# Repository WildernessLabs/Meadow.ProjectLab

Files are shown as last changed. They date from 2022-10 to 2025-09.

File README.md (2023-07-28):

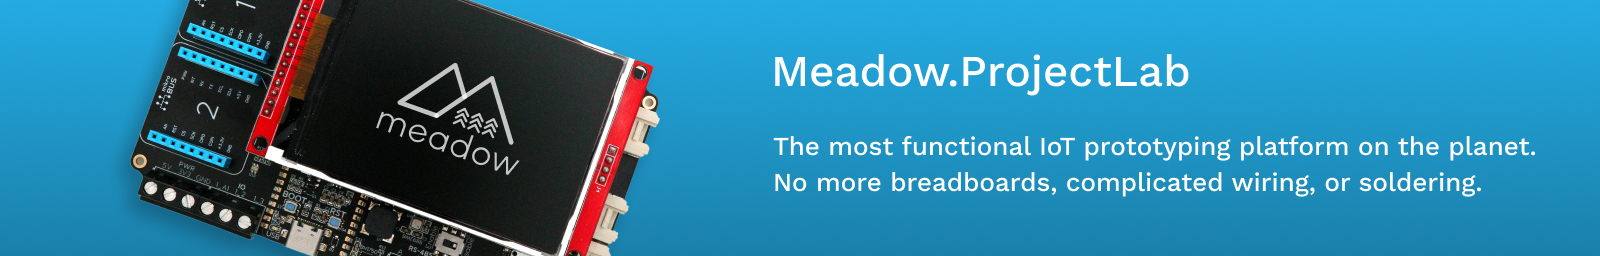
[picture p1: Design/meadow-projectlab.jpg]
Meadow.ProjectLab, C#, iot


# Meadow.ProjectLab

Project Lab is the most functional IoT prototyping platform on the planet. No more breadboards, complicated wiring, or soldering. Project Lab was built from the ground up using the industry's most powerful, capable, and reliable sensors, components, and connectors.

## Contents
* [Purchasing or Building](#purchasing-or-building)
* [Getting Started](#getting-started)
* [Hardware Specifications](#hardware-specifications)
* [Pinout Diagram](#pinout-diagram)
  * [Project Lab v3.e](#project-lab-v3e)
  * [Project Lab v2.e](#project-lab-v2e)
  * [Project Lab v1.e](#project-lab-v1e)
* [Industrial Enclosure Design](#industrial-enclosure-design)
* [Additional Samples](#additional-samples)
* [Support](#support)

## Purchasing or Building

<table width="100%">
    <tr>
        <td>
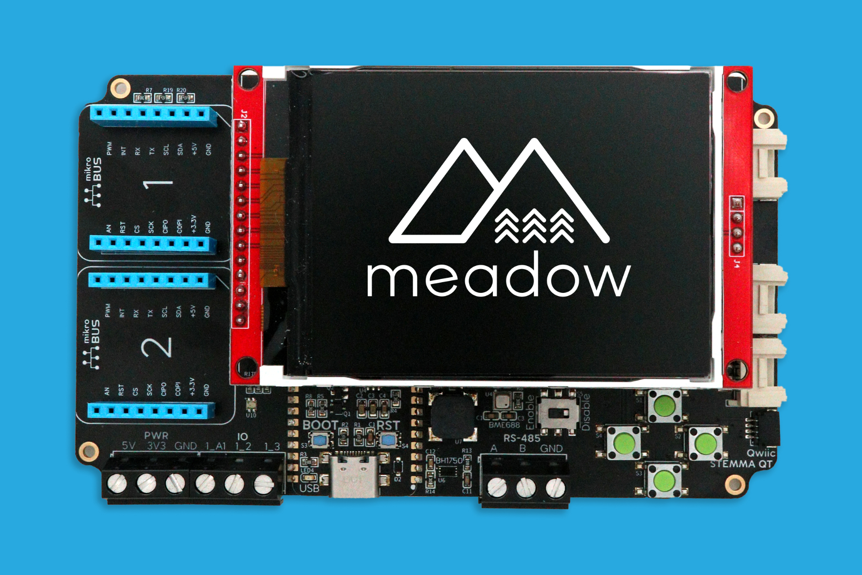
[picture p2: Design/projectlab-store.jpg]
ProjectLab, C#, iot
            
        </td>
        <td>
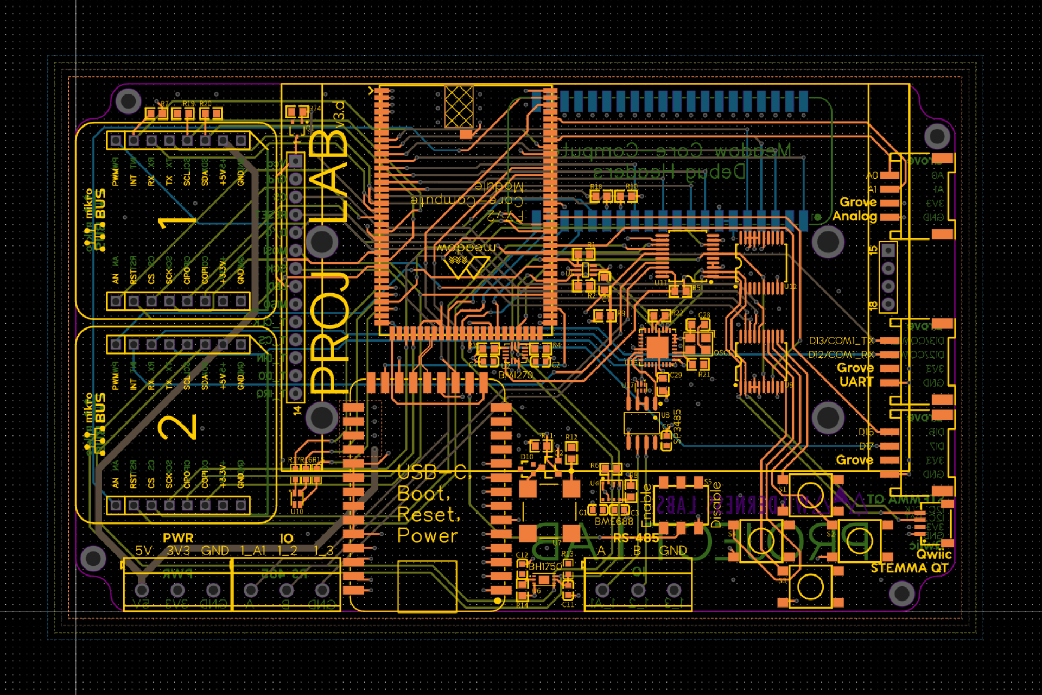
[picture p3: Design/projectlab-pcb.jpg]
ProjectLab, C#, iot
             
        </td>
    </tr>
    <tr>
        <td>
            You can get a Project Lab fully assembled from the <a href="https://store.wildernesslabs.co/collections/frontpage/products/project-lab-board">Wilderness Labs store</a>.
        </td>
        <td> 
            It's also designed so that it can be assembled at home for the adventurous. All design files can be found in the <a href="/Hardware">Hardware Design</a> folder.
        </td>
    </tr>
</table>

## Getting Started

To make using the hardware even simpler, we've created a Nuget package that instantiates and encapsulates the onboard hardware into a `ProjectLab` class.

1. Add the ProjectLab Nuget package your project: 
    - `dotnet add package Meadow.ProjectLab`, or
    - [Meadow.ProjectLab Nuget Package](https://www.nuget.org/packages/Meadow.ProjectLab)
    - [Explore in Fuget.org](https://www.fuget.org/packages/Meadow.ProjectLab/0.1.0/lib/netstandard2.1/ProjectLab.dll/Meadow.Devices/ProjectLab)

2. Instantiate the `ProjectLab` class:  
```csharp
public class MeadowApp : App<F7FeatherV2>
{
    IProjectLabHardware projLab;

    public override Task Initialize()
    {
        projLab = ProjectLab.Create();
        ...
```

3. To Access the `Project Lab` onboard peripherals:
```csharp
    if (projLab.EnvironmentalSensor is { } bme688)
    {
        bme688.Updated += Bme688Updated;
        bme688.StartUpdating(TimeSpan.FromSeconds(5));
    }
```

4. To use an I2C peripheral (with a [Grove Character display](https://wiki.seeedstudio.com/Grove-16x2_LCD_Series) as an example):
```csharp
    var display = new CharacterDisplay
    (
        i2cBus: projLab.I2cBus,
        address: (byte)I2cCharacterDisplay.Addresses.Grove,
        rows: 2, columns: 16,
        isGroveDisplay: true
    );
```

## Hardware Specifications

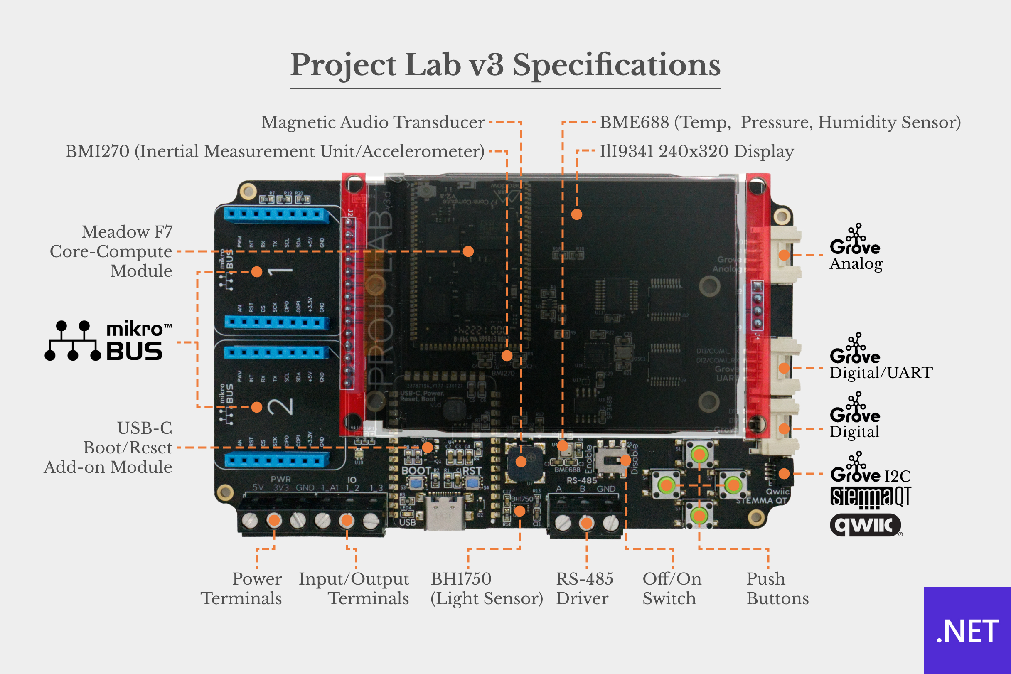
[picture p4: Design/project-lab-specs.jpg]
project-lab, specs, iot, dotnet


<table>
    <tr>
        <th>Onboard Peripherals</th>
        <th>Connectivity</th>
    </tr>
    <tr>
        <td><strong>ILI9341</strong> - SPI 320x240 color display</li></td>
        <td><strong>MikroBUS</strong> - Two sets of MikroBUS pin headers</td>
    </tr>
    <tr>
        <td><strong>BMI270</strong> - I2C motion and acceleration sensor</td>
        <td><strong>Qwiic</strong> - Stemma QT I2C connector</td>
    </tr>
    <tr>
        <td><strong>BH1750</strong> - I2C light sensor</td>
        <td><strong>Grove</strong> - Analog header</td>
    </tr>
    <tr>
        <td><strong>BME688</strong> - I2C atmospheric sensor</td>
        <td><strong>Grove</strong> - GPIO/serial header</td>
    </tr>
    <tr>
        <td><strong>Push Button</strong> - 4 momentary buttons</td>
        <td><strong>RS-485</strong> - Serial</td>
    </tr>
    <tr>
        <td><strong>Magnetic Audio Transducer</strong> - High quality piezo speaker</td>
        <td><strong>Ports</strong> - 3.3V, 5V, ground, one analog and two GPIO ports</td>
    </tr>
</table>

You can find the schematics and other design files in the [Hardware folder](/Hardware).

## Pinout Diagram

Check the diagrams below to see what pins on the Meadow are connected to every peripheral on board and its connectors:
&nbsp;

### Project Lab v3.e

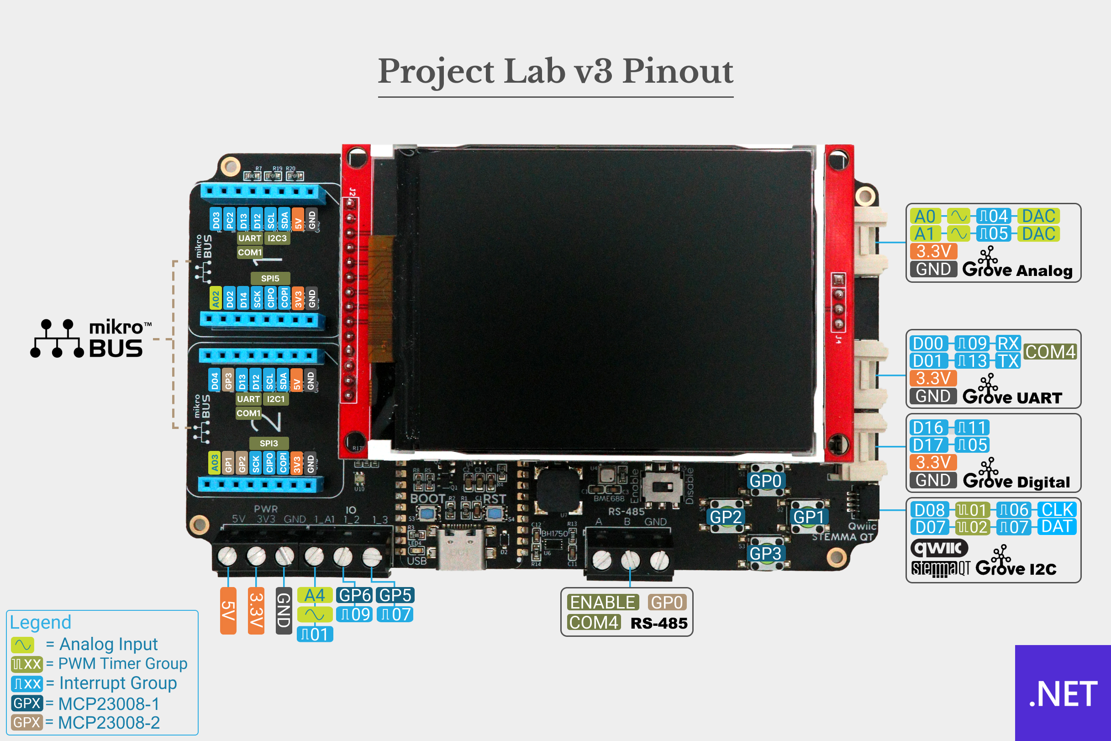
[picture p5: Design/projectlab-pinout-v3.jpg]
project-lab-v3, pinout, iot, dotnet


### Project Lab v2.e

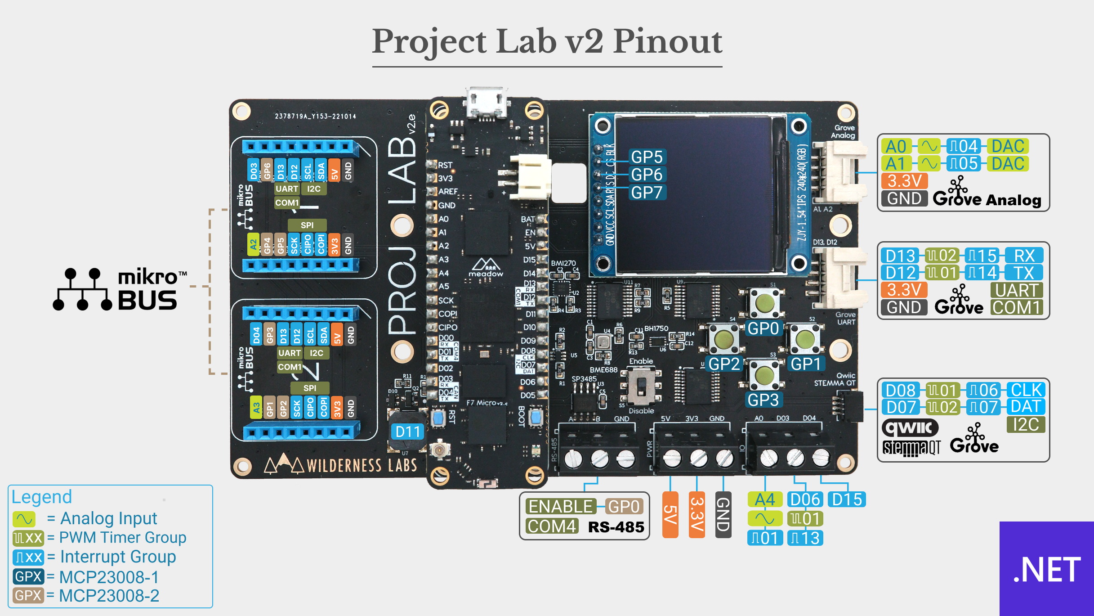
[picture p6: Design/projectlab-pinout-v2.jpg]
project-lab-v2, specs, iot, dotnet


### Project Lab v1.e

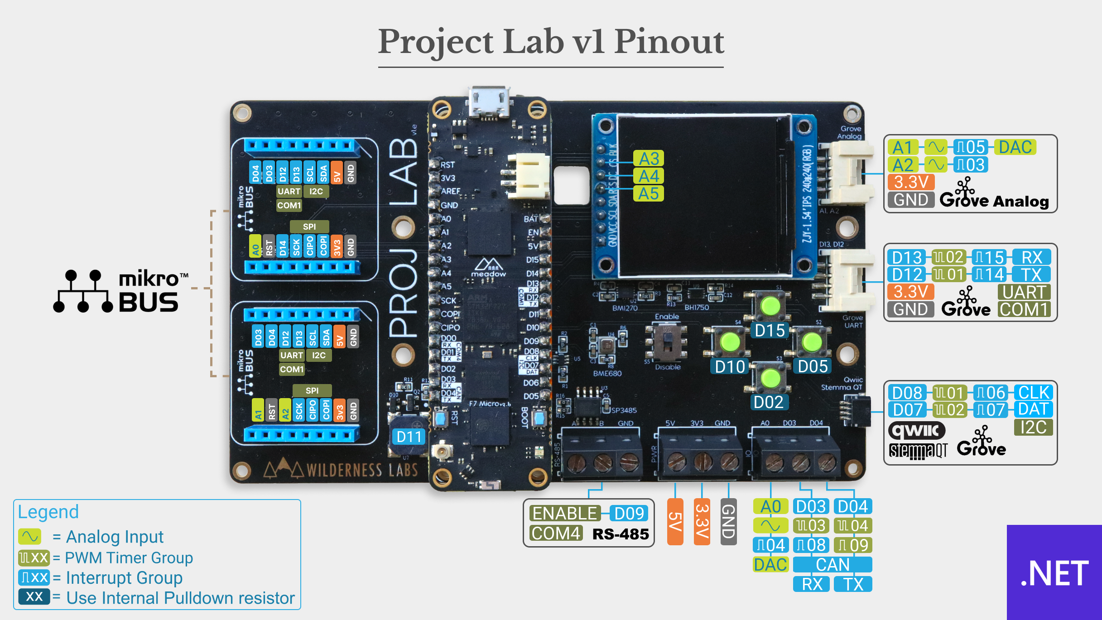
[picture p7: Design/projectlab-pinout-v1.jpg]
project-lab-v1, specs, iot, dotnet


## Industrial Enclosure Design

The enclosure was designed in Autodesk Fusion 360. The source file can be found and STL files can be found [here](Design/Enclosure/STLs_For_Printing/).

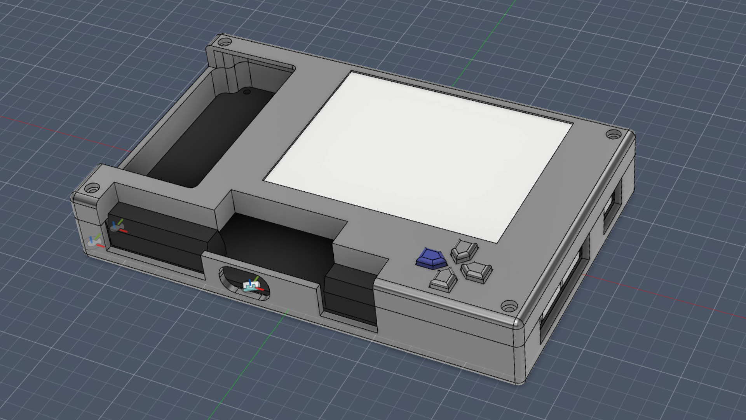
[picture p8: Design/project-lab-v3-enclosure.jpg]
project-lab, enclosure, 3d-print, iot


## Additional Samples

1. **[Setup your Meadow Build Environment](http://developer.wildernesslabs.co/Meadow/Getting_Started/Deploying_Meadow/)** - If you haven't deployed a Meadow app before, you'll need to setup your IDE extension(s), deploy Meadow.OS, etc.
2. **[Run the Demo App](Source/ProjectLab_Demo)** - Deploy the Project Lab demonstration app to see the built in peripherals at work.
3. **[Check out the Project Lab Samples](https://github.com/WildernessLabs/Meadow.ProjectLab.Samples)** - We recommend cloning the [Meadow.ProjectLab.Samples](https://github.com/WildernessLabs/Meadow.ProjectLab.Samples) repo. There you'll find a bunch of awesome samples that you can run right out-of-the box! 
<a href="https://github.com/WildernessLabs/Meadow.ProjectLab.Samples">
    project-lab, iot, project, samples
</a>

## Support

Having trouble building/running these projects? 
* File an [issue](https://github.com/WildernessLabs/Meadow.Desktop.Samples/issues) with a repro case to investigate, and/or
* Join our [public Slack](http://slackinvite.wildernesslabs.co/), where we have an awesome community helping, sharing and building amazing things using Meadow.

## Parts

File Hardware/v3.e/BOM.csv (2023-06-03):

ID | Name | Designator | Footprint | Quantity | Manufacturer Part | Manufacturer | Supplier | Supplier Part | Price
1 | 0.1u | C1,C2,C3,C4,C5,C11,C12 | C0603 | 7 | CC0603KRX7R9BB103 | Yageo
2 | 0.1µf | C7 | C0603 | 1 | CC0603KRX7R7BB104 | YAGEO | LCSC | C108079 | 0.003
3 | 0.1u | C28,C29 | C0603 | 2 | CC0603KRX7R7BB104 | Yageo
4 | SM04B-SRSS-TB (LF)(SN) | CN1 | CONN-SMD_4P-P1.00_SM04B-SRSS-TB-LF-SN | 1 | SM04B-SRSS-TB (LF)(SN) | JST Sales America | LCSC | C160404 | 0.178
5 | BAS70KFILM | D10 | SOT323 | 1 | BAS70KFILM | ST Microelectronics
6 | 1125R-SMT-4P | J1,J2,J3 | HW4-SMD-2.0-90D | 3 | 1125R-SMT-4P
7 | 1.8432MHz | OSC1 | OSC-SMD_4P-L3.2-W2.5-CJ13-320001210A20 | 1 | ASE-1.8432MHZ-LC-T | ABRACON
8 | CONN-TH_3P-P5.00 | P1,P2,P3 | CONN-TH_3P-P5.00 | 3 | 39890-0303 | Molex | Digi-Key | WM15826-ND
9 | MCH3374-TL-E | Q1 | -ONSC-MCPH-3_V | 1 | MCH3374-TL-E | OnSemi
10 | FDV305N | Q2 | SOT-23_L2.9-W1.3-P0.95-LS2.4-BR | 1 | FDV305N | Fairchild |  | C65189 | 0.034
11 | 10k | R1,R2,R3,R4,R5,R6,R7,R8,R9,R14,R21,R74 | R0603 | 12 | RC0603FR-0710KL | Yageo
12 | 0 | R10,R18 | R0603 | 2 | RC0603JR-070RL | Yageo
13 | 10kΩ | R11 | R0603 | 1 | RC0603FR-0710KL | Yageo
14 | 20Ω | R12 | R0603 | 1 | RC0603FR-0720RL | Yageo
15 | 1k | R13,R22 | R0603 | 2 | RC0603FR-071KL | Yageo
16 | 300 | R15,R16 | R0603 | 2 | RC0603FR-07300RL | Yageo
17 | 620 | R17 | R0603 | 1 | RC0603FR-07620RL | Yageo
18 | 4.7kΩ | R19,R20 | R0603 | 2 | RC0603FR-074K7L | Yageo
19 | Up | S1 | TACTILE_SWITCH_TALL | 1
20 | Down | S2,S3,S4 | TACTILE_SWITCH_TALL | 3
21 | 452403012014 | S5 | 452403012014 | 1 | 452403012014 | Wurth Elektronik
22 | Meadow F7v2 Core-Compute Module - Logical | U1 | MEADOW_F7V2_CORE_COMPUTE | 1 |  | Wilderness Labs
23 | BMI270 | U2 | LGA-14_L3.0-W2.5-P0.50-BR | 1 | BMI270 | null | LCSC | C2836813 | 1.877
24 | SP3485CN-L | U3 | SOIC-8_L4.9-W3.9-P1.27-LS6.0-BL | 1 | SP3485CN-L | MaxLinear | LCSC | C916153 | 7.804
25 | BME688 | U4 | LGA-8_L3.0-W3.0-P0.80-TR | 1 | BME688 | Bosch Sensortec
26 | LTC4311ISC6 | U5 | SC-70-6_L2.2-W1.3-P0.65-LS2.2-BL | 1 | LTC4311ISC6#TRPBF
27 | BH1750FVI-TR | U6 | WSOF-6_L2.6-W1.6-P0.50-TL-EP | 1 | BH1750FVI-TR | ROHM | LCSC | C78960 | 0.942
28 | CMT-7525-80-SMT | U7 | CMT-7525S | 1 | CMT-7525-80-SMT | CUI Devices
29 | MCP23008T-E/SS | U9,U11,U12 | SSOP-20_L7.2-W5.3-P0.65-LS7.8-TL | 3 | MCP23008T-E/SS | Microchip Tech | LCSC | C629435 | 1.979
30 | LTST-C19HE1WT | U10 | LED-ARRAY-SMD_0603-4P-L1.6-W1.6-BL-RD | 1 | LTST-C19HE1WT-H | Lite-On | LCSC | C427425 | 0.066
31 | Meadow Core-Compute USB-C, Power, Boot, and Reset Addon Module | U13 | MEADOW CORE-COMPUTE USB-C, POWER, BOOT, RESET ADDON MODULE | 1 |  | Wilderness Labs
32 | ILI9341 LCD TFT 3.2 | U14 | ILI9341 TFT LCD 3.2" - NO BOLT HOLES | 1 | ILI9341 LCD TFT 3.2
33 | MEADOW F7 DEBUG ADDON MODULE | U15 | MEADOW F7 DEBUG ADDON MODULE | 1
34 | SC16IS752IBS,128 | U16 | HVQFN-32_L5.0-W5.0-P0.50-TL-EP3.1 | 1 | SC16IS752IBS,128 | NXP(恩智浦) | LCSC | C2678025 | 5.306
35 | NC7S04L6X | U17 | MICROPAK-6_L1.5-W1.0-P0.50-BR | 1 | NC7S04L6X | onsemi(安森美) | LCSC | C895519 | 0.189

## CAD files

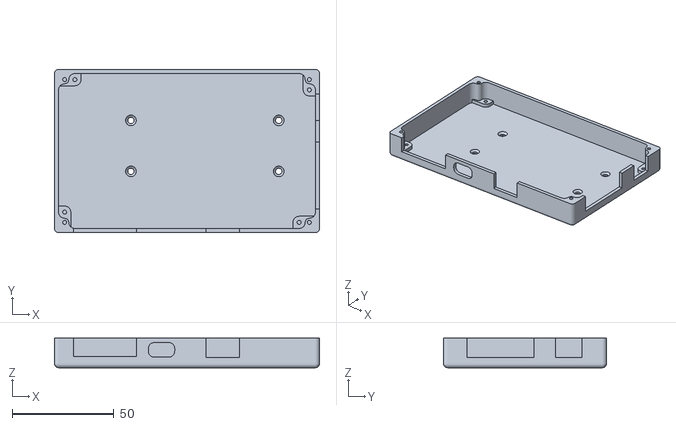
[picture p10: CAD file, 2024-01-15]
Design/Enclosure/STLs_For_Printing/PL_Enclosure_Bottom_w_DIN_Mount.stl
130.0 x 80.0 x 14.5

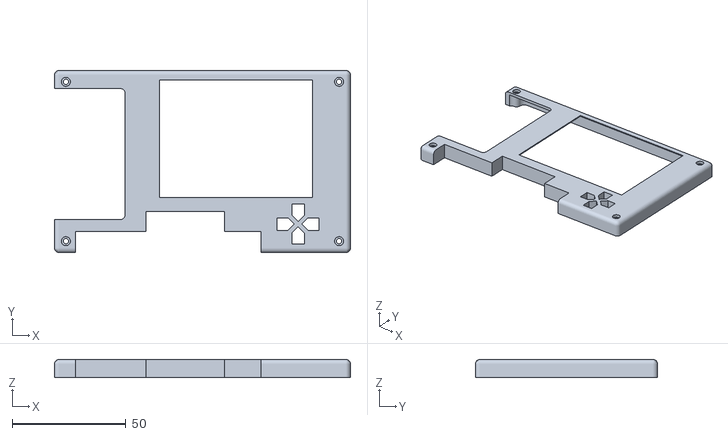
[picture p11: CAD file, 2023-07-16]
Design/Enclosure/STLs_For_Printing/PL_Enclosure_Top.stl
130.0 x 80.0 x 8.00

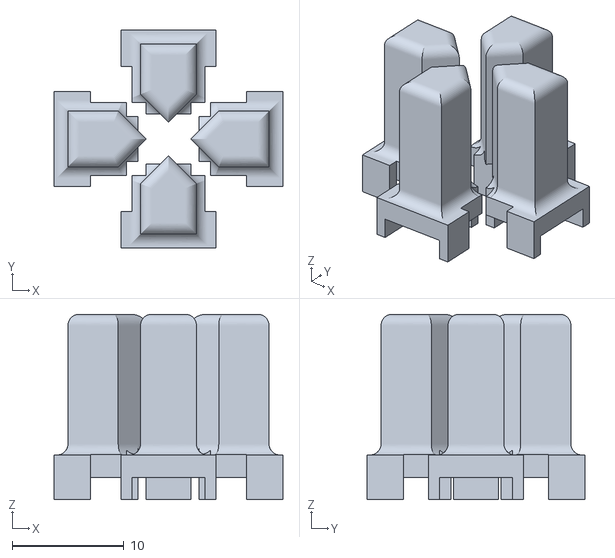
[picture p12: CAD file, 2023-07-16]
Design/Enclosure/STLs_For_Printing/PL_D-Pad_2.stl
20.5 x 19.5 x 16.6

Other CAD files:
Design/Enclosure/STLs_For_Printing/PL_Enclosure_Bottom.stl
Design/Enclosure/Source/PLv3 Enclosure w DIN Mounts.f3z
Design/Enclosure/Source/PLv3 Enclosure.f3z

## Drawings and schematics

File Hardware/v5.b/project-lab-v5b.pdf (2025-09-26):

# I2C1 Accelerator + Pull-ups

# Grove Analog/Digital

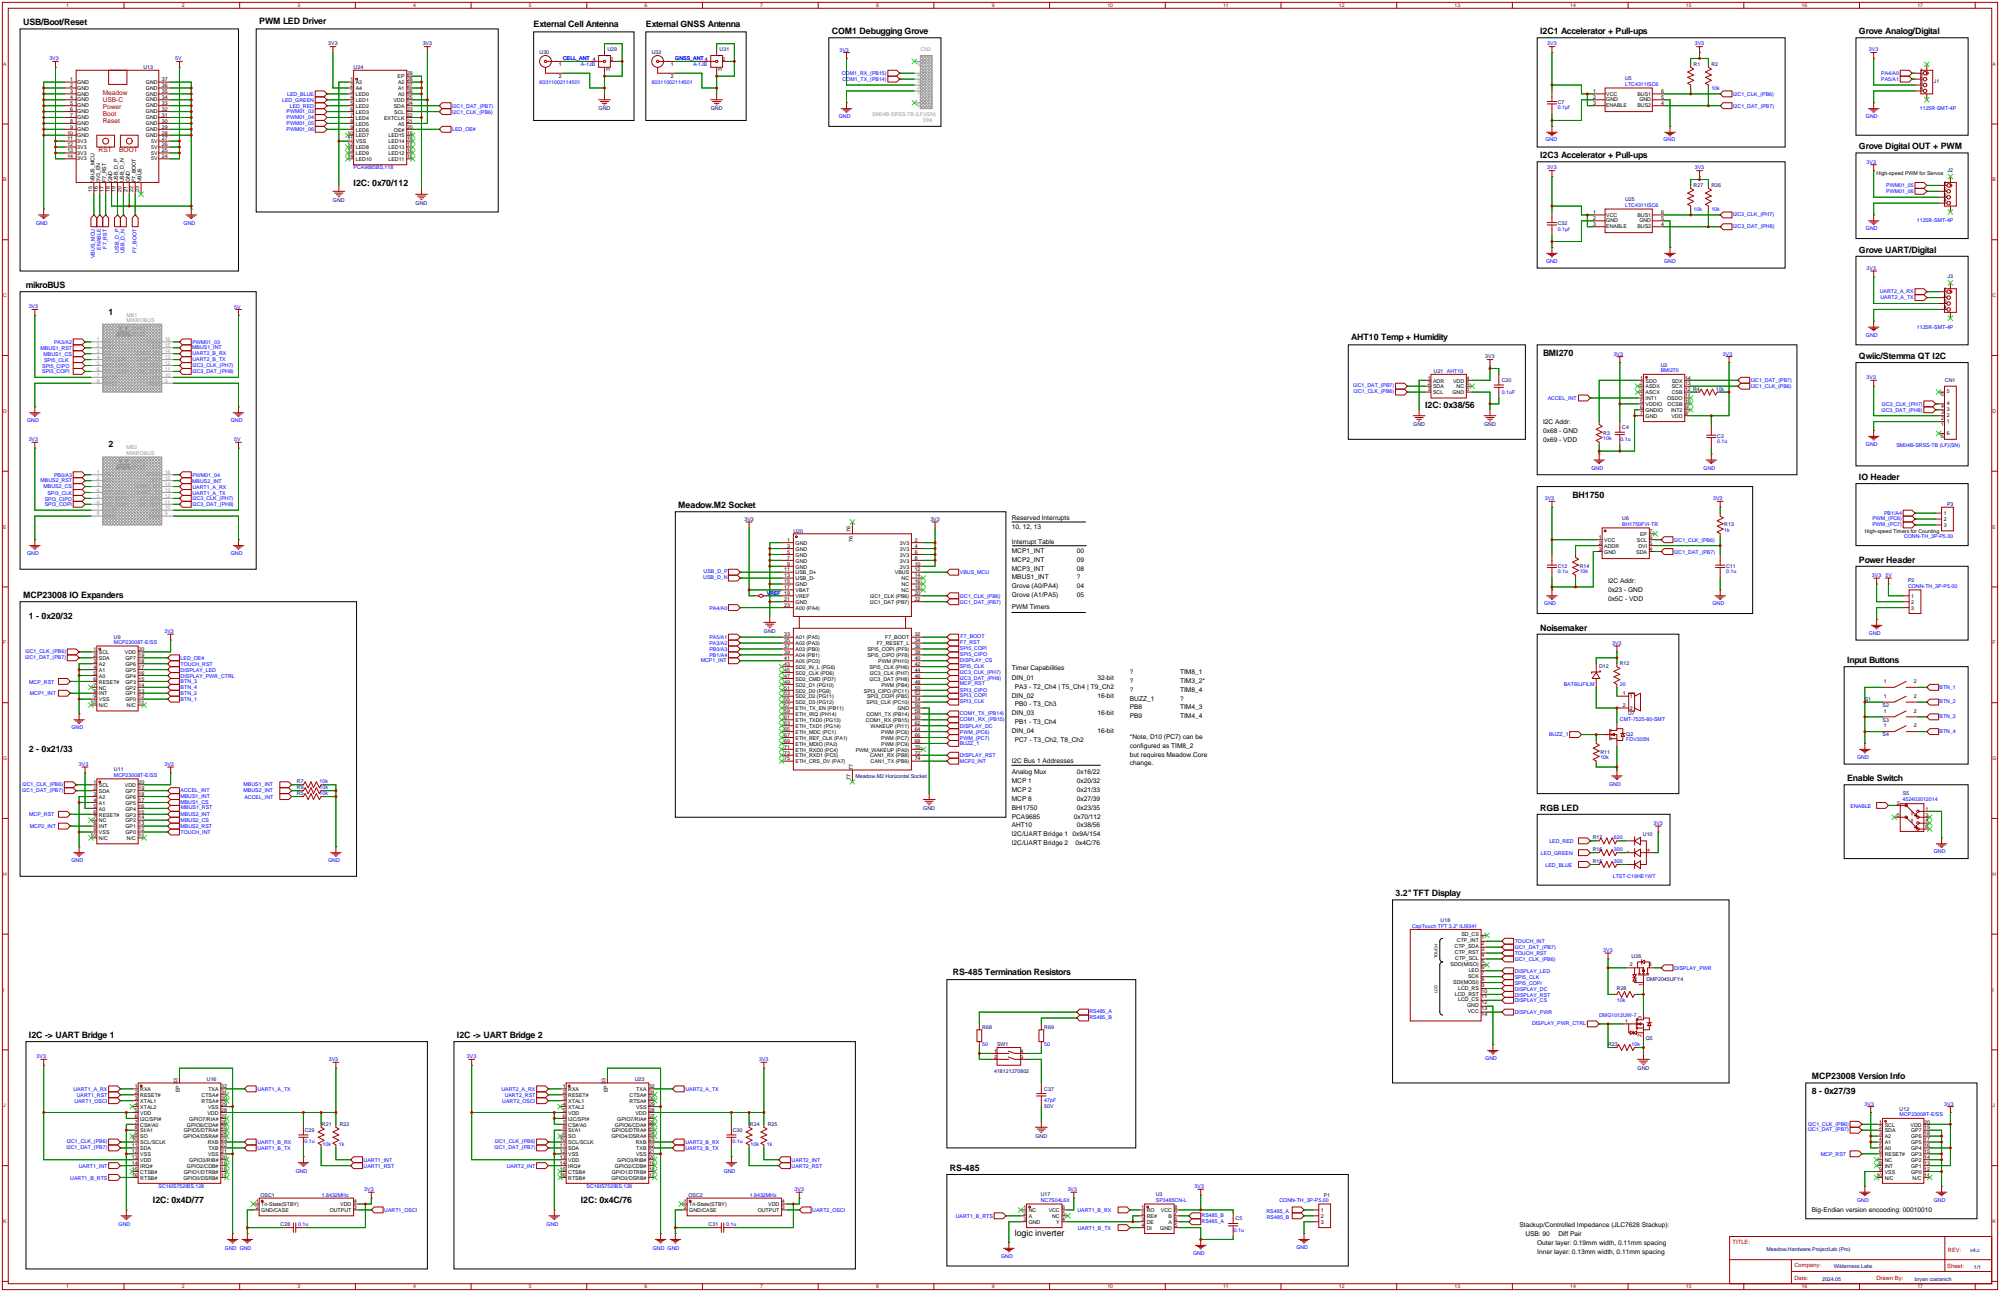
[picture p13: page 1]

5V 24 5V 25 5V 26 5V 27 GND 28 GND 29 GND 30 GND 31 GND 32 GND 33 GND 34 GND 35 GND 36 GND 37

SM04B-SRSS-TB (LF)(SN)

Grove Digital OUT + PWM

*Note, D10 (PC7) can be
configured as TIM8_2
but requires Meadow.Core
change.

Big-Endian version encooding: 00010010

Stackup/Controlled Impedance (JLC7628 Stackup):
USB: 90 Diff Pair
Outer layer: 0.19mm width, 0.11mm spacing
Inner layer: 0.13mm width, 0.11mm spacing

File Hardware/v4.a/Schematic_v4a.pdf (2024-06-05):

BME 688 | 3V3

# I2C Accel Pull-Ups

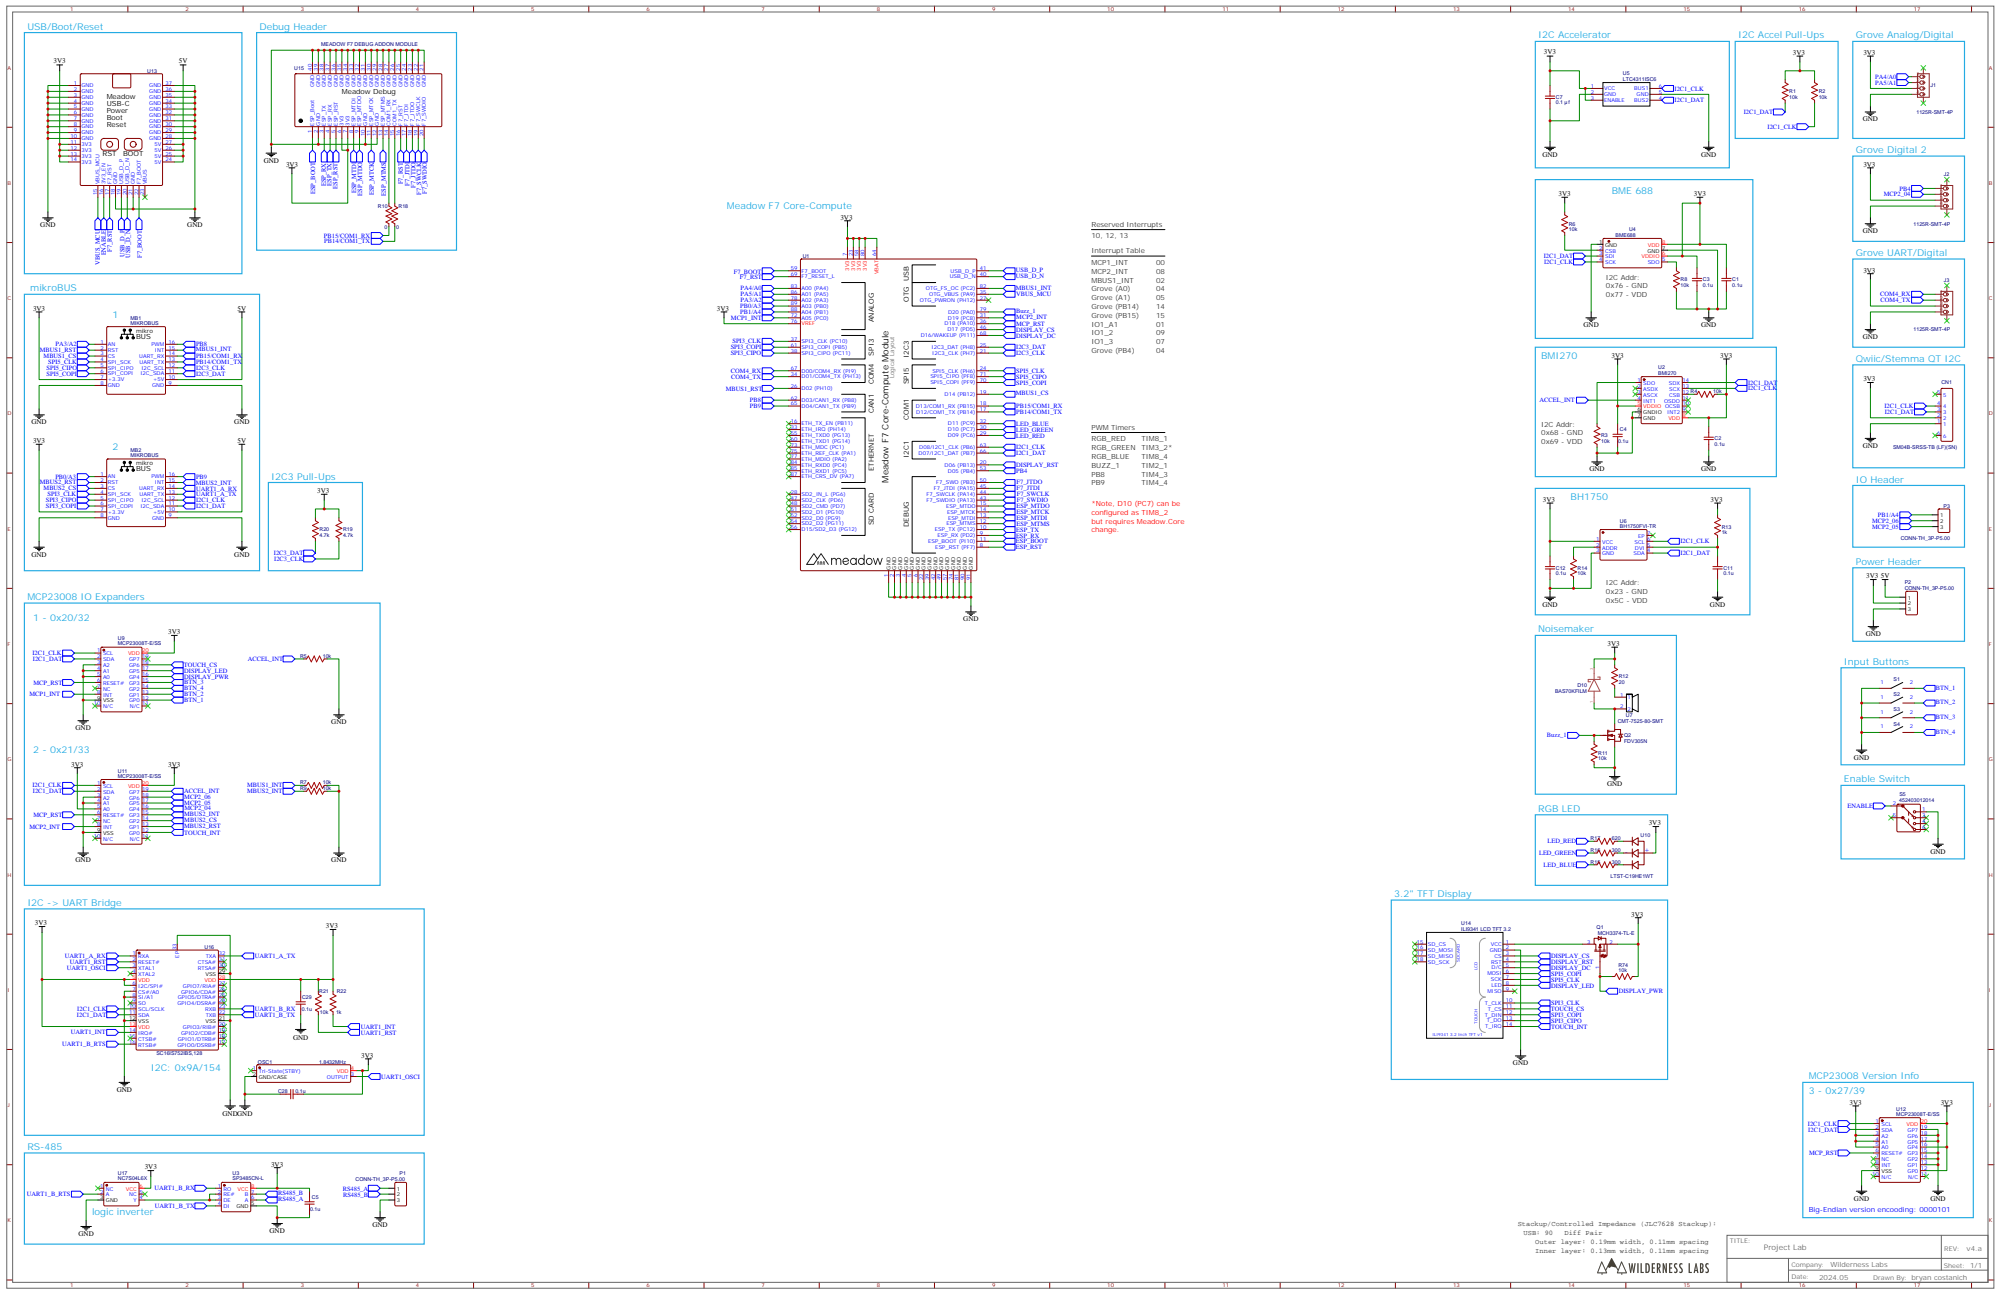
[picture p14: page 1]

MEADOW F7 DEBUG ADDON MODULE

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

F7_SWDIO 20 GND 21 GND 22 GND 23 GND 24 GND 25 GND 26 GND 27 GND 28 GND 29 GND 30 GND 31 GND 32 GND 33 GND 34 GND 35 GND 36 GND 37 GND 38 GND 39 GND 40

Meadow F7 Core-Compute Module

GND 6 GND 5 GND 4 GND 3 GND 2 GND 1 Logical Layout

SM04B-SRSS-TB (LF)(SN)

*Note, D10 (PC7) can be
configured as TIM8_2
but requires Meadow.Core
change.

Big-Endian version encooding: 0000101

Stackup/Controlled Impedance (JLC7628 Stackup):
Outer layer: 0.19mm width, 0.11mm spacing
Inner layer: 0.13mm width, 0.11mm spacing

Drawn By: bryan costanich

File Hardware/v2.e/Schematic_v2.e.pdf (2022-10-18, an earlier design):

# I2C Pull-Ups

## Interrupt Table

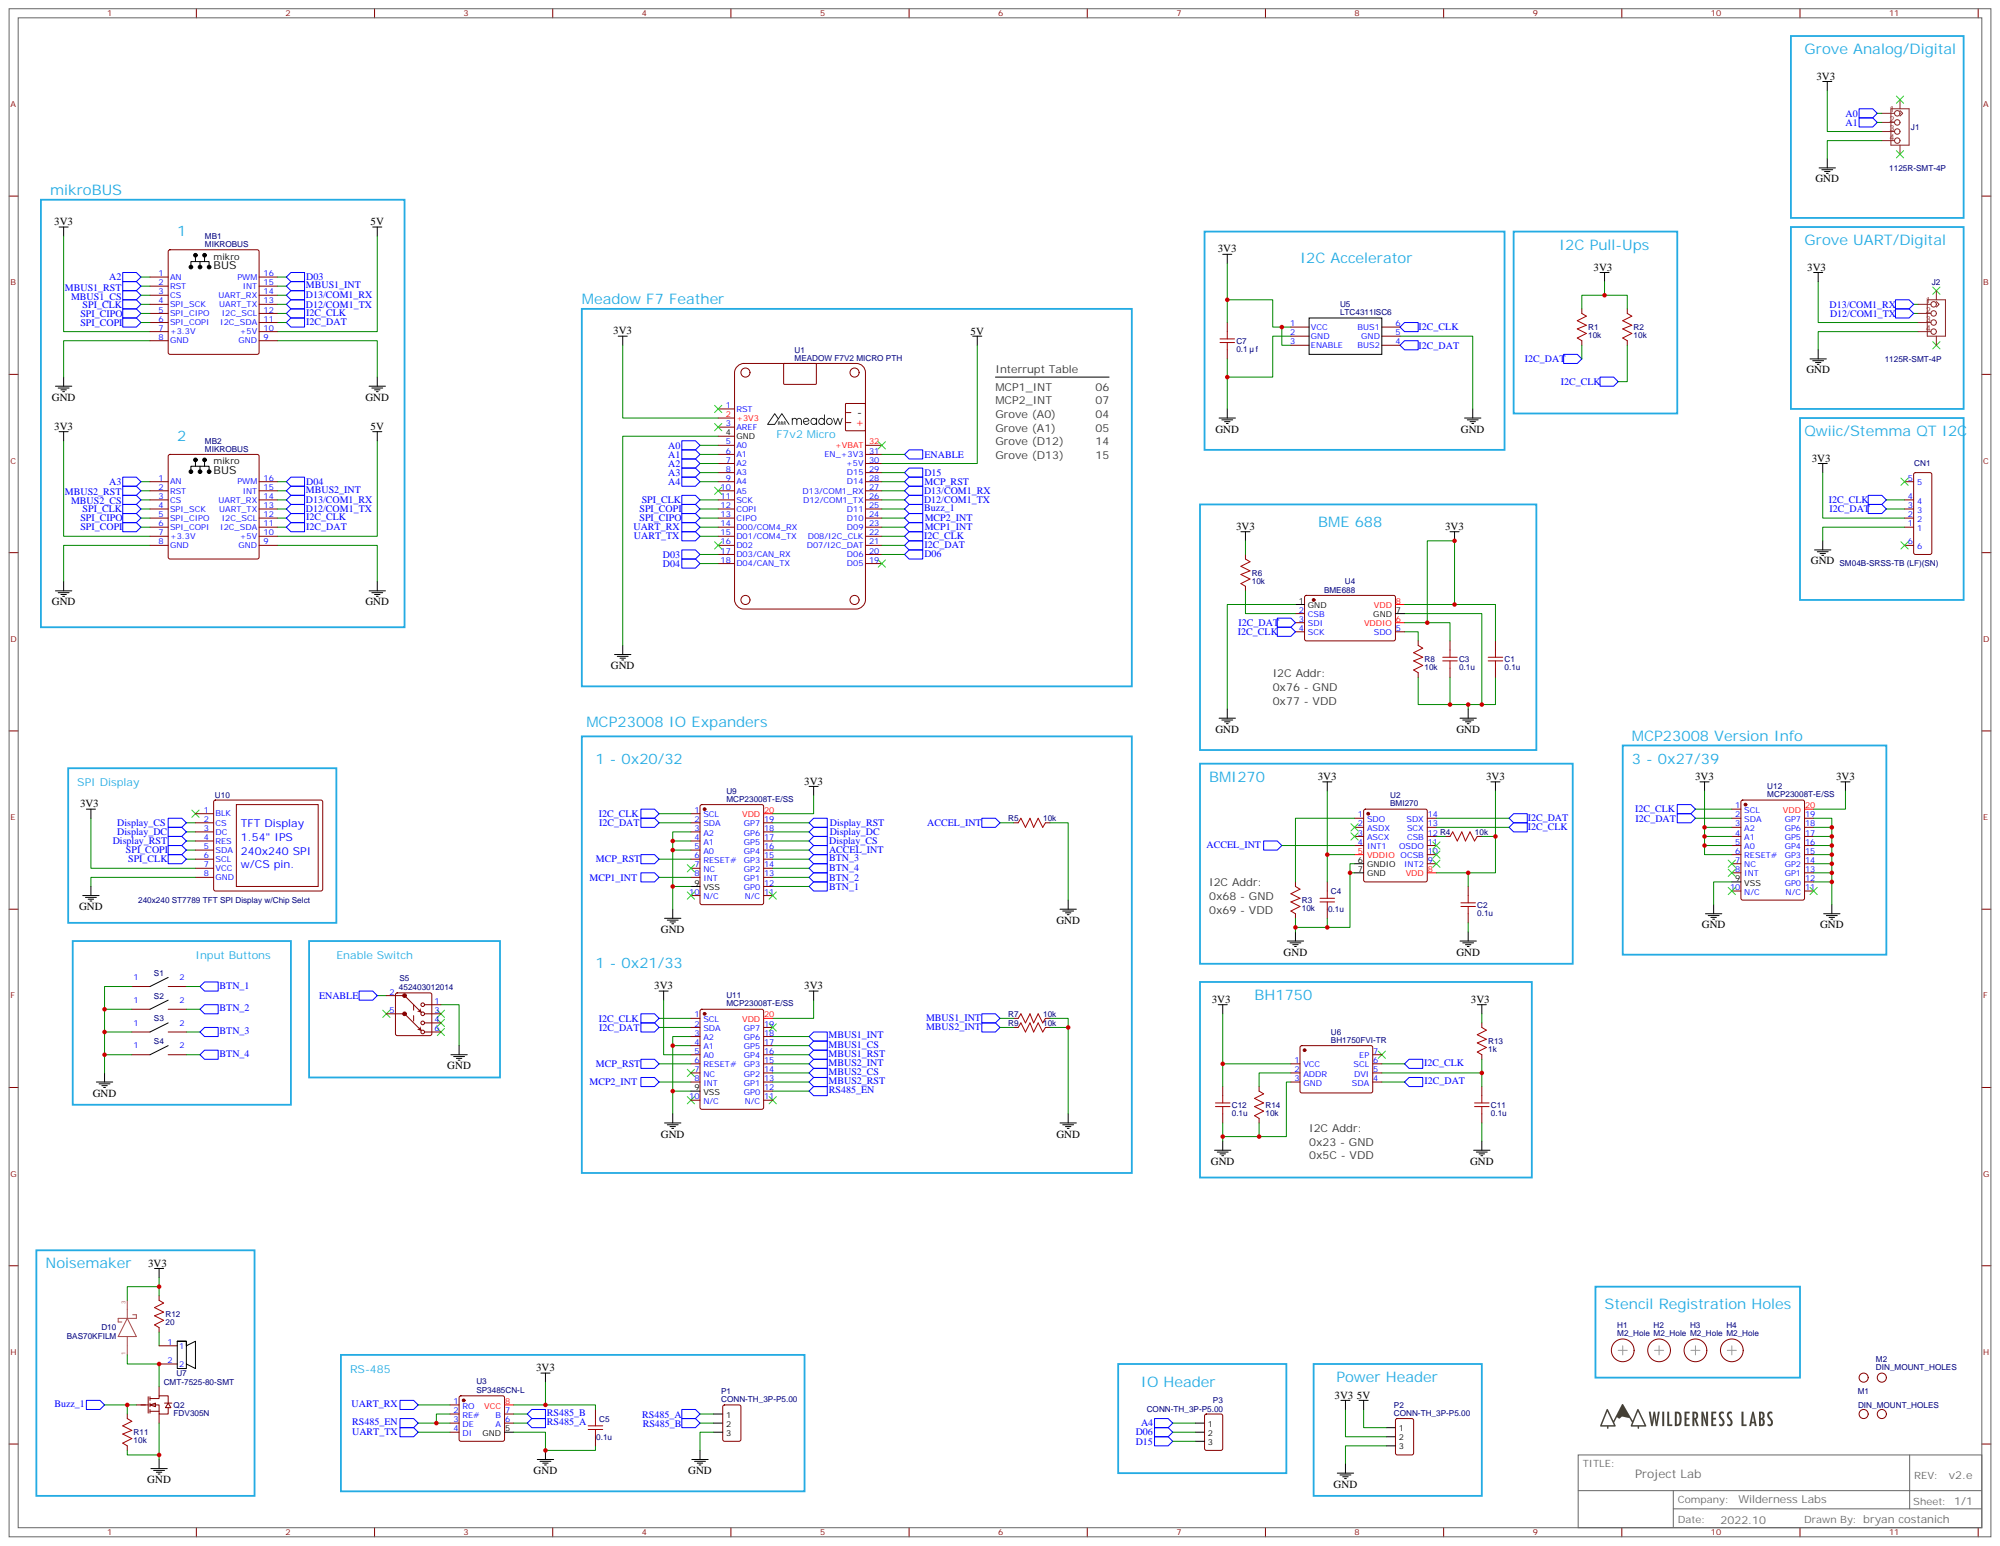
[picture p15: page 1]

GND
SM04B-SRSS-TB (LF)(SN)

240x240 ST7789 TFT SPI Display w/Chip Selct

Power Header IO Header

Drawn By: bryan costanich

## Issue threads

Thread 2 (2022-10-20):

Add FET to Display `VIN` to be able to turn it off.

bryancostanich, 2022-10-20:
Also add PWM to backlight

bryancostanich, 2024-01-11:
Fixed in v3.a

Closed 2024-01-11.

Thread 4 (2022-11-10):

Pinout Diagram: Add UART/COM names

bryancostanich, 2022-11-10:
in the pinout diagram, it has the pin numbers for the UART/Serial IOs, but it doesn't have the name, i.e. `COM4`, so it requires a lookup on the meadow pinout diagram.

would be nice if the serial port names were on it.

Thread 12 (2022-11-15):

Check interrupt capabilities for 2nd MCP interrupt port

adrianstevens, 2022-11-15:
D10 doesn't support interrupts on Feather V1 ..... check capabilities and skip interrupt ports to unlock RS-485 and Mikrobus functionality for Meadow V1 boards connected to Proj Lab v2

https://github.com/WildernessLabs/Meadow.ProjectLab/blob/develop/Source/Meadow.ProjectLab/ProjectLab.cs#L87

bryancostanich, 2024-01-11:
@adrianstevens this is for the old Project Lab yeah?

adrianstevens, 2024-01-12:
@bryancostanich yeah old Project Lab so I vote we close

Closed 2024-01-12.

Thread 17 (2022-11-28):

Pinout Diagram: Analog Grove Pins are Incorrect

bryancostanich, 2022-11-28:
Diagram says the Analog pins on the Grove Analog connector are `A1` and `A2`, but they are in face `A00`, and `A01`.

jorgedevs, 2022-11-28:
Pinout corrected and available in the next release

Closed 2022-11-28.

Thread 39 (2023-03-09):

Device.CreateSerialPort does not set Parity correctly

fredmbarrett, 2023-03-09:
When creating a SerialPort using Device.CreateSerialPort() method, the Parity is not set correctly, specifically with Parity.Even.

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

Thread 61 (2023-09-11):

ProjLabV3 - Tx and Rx are crossed on the ESP32 debug headers

NevynUK, 2023-09-11:
Connected the ProjLabV3 board to ESP-PROG using an straight through IDC cable and there are no UART activity.

Using Dupont cable and crossing Tx and Rx worked.

bryancostanich, 2024-01-11:
fixed in v3.f

Closed 2024-05-01.

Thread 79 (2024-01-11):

Remove DIN Mounts

bryancostanich, 2024-01-11:
They interfere with the PTH solder joints of the display and they're better handled on the enclosure rather than mounting a raw PCB to a DIN rail.

bryancostanich, 2024-01-11:
fixedin v3.f

Closed 2024-05-01.

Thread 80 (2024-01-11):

Grove D2 lacks PWMs

bryancostanich, 2024-01-11:
Suggest:
-> Expose PB4 on the Grove Digital 2 header
-> Move MCP_RST to another pin

bryancostanich, 2024-01-11:
fixed in the upcoming v3.f

Closed 2024-05-01.

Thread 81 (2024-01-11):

Upgrade the USB-C Addon Module

bryancostanich, 2024-01-11:
The new USB-C addon module has a breaking pin change, so the Project Lab needs to be updated with the new symbol and footprint.

The new USB-C addon module is being assembled in bulk, so this will help optimize the assembly of Project Labs.

bryancostanich, 2024-01-11:
fixed in v3.f

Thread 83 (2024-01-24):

Display `LED` is connected to `PWR`

ctacke, 2024-01-24:
The display backlight is controlled by the `LED` pin.  On the 3.e, this is tied to the `PWR` pin, so to turn off the backlight, you must turn off power to the display.  This causes the display to reset and lose its configuration, so when it gets powered, it just comes up white.  The workaround is ugly - it requires re-creating the display driver instance on wake, which has its own set of challenges.

The `LED` pin needs to be run to its own GPIO (and after that, the code set to initialize that pin high).

My current workaround was to clip the `LED` pin off of the physical display, and run a bodge wire to a pin on the Mikrobus port

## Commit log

2022-10-18 Added BoM
    [BOM_v2.e.csv]
2022-10-19 Migrated Projectlab library from Samples
2022-10-23 Switch to NuGet references
2022-11-10 Update pinout diagram to indicate COM ports for Grove and mikroBUS connectors
2022-11-11 fix v1 pushbutton to support interrupt or non-interrupt pins
2022-11-13 Repo re-structure like our other repos
    [BOM_v2.e.csv]
2022-11-13 Add PushButtons support for ProjLabs v1 boards using polling
2022-11-13 Add Mcp23xxx NuGet, and add Meadow.Foundation.Core project reference (add polling Push Buttons on V1)
2022-11-15 Only create an interrupt port for Mcp2 if the pin supports it
2022-11-19 Switch to local refs and remove build configurations
2022-11-28 Fix Analog pins on the V1 Pinout and add link to PL samples from the image
2023-01-24 Switch ProjLab to local refs for active development
2023-02-03 Switch to local refs
2023-02-07 Add MikroBus pin definitions to hardware interface and V1/V2 implementations
2023-02-08 Update ProjectLab_Demo for new pin controller pattern
2023-03-14 Add display enable pin for V3
2023-03-30 Bump V3 SPI to 48000
2023-04-29 Add Led support, MicroAudio to demo and update for v3d
2023-05-06 Add v3d schematic
2023-05-06 Mikrobus pin definition cleanup
2023-05-31 refactor required by interrupt port
2023-06-03 reorganized hardware designs and added v3.e files
    [BOM.csv, BOM_v2.e.csv]
2023-06-27 Update button properties to IButton and update v1 to use polling buttons
2023-07-11 uart support on 3.e
2023-07-12 added uart project
2023-07-12 connector defs
2023-07-12 removing old mikrobus pin stuff
2023-07-13 more connector work
2023-07-13 validating 3e connectors
2023-07-16 Added Enclosure Files
    [PL_D-Pad_2.stl, PL_Enclosure_Bottom.stl, PL_Enclosure_Top.stl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]
2023-07-18 Gove digital connector updates
2023-07-25 Add additional connectors
2023-07-27 Pin map SPI fix for mikrobus port 2
2023-07-28 Add support and enclosure section
2023-09-21 Add IO terminal connector + Qwiic connector cleanup
2023-10-01 Add display connector + XML comments
2023-10-02 Fix connector array size
2023-10-02 Add XML comment for connector collection
2023-10-03 bug fix: A0 (I/O connector pin 1) wrong on PL v2
2023-10-19 Lazy load a few sensors
2023-10-19 push sensors to sensor service
2023-10-25 cleanup
    fix nullability warnings
    simplify/improve xmldocs
    Trace vs Debug
    update/align revision string logic
2023-11-28 Fixing light sensor
2024-01-15 Added enclosure with DIN mounts
    [PL_Enclosure_Bottom_w_DIN_Mount.stl, PLv3 Enclosure w DIN Mounts.f3z]
2024-02-02 Add gyro data to display controller
2024-02-03 Add gas resistance sensor support
2024-02-03 Update atmospheric sensor name
2024-02-03 Update bme688 sensor service registration for clarity
2024-06-04 Set the correct SPI bus for the display on V4 hardware + minor cleanup
2024-06-04 Fix touch interrupt
2024-06-10 Remove MCP23008 port state hack and correctly set SPI bus speed
2024-07-25 Add v4b schematic
2025-01-12 Add 2nd temperature sensor to ProjectLab
2025-01-12 Minor xml comment update for 2nd temp sensor
2025-03-11 Fix SPI and I2C mikrobus connector mappings for v4
2025-04-06 uart expander problems no longer crash the entire app
2025-06-16 better handling of uart expander failure
2025-07-01 added RS485 connector
2025-07-03 more 485 connector work
2025-07-03 bug fix for connector count/threading
2025-08-08 Adding pin fixes for v5.b
2025-08-12 Fix v5b reset pin
2025-09-01 Init RGB led to off for v5 hardware
2025-09-26 added v5b schematic
